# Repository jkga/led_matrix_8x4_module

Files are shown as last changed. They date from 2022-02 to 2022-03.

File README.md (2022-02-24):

# LED Matrix(8x4) Module
This repository aims to provide a basic program, schematic diagram, and PCB design for  an eight by four (8x4) LED matrix with Arduino and SN74HC595 shift register IC

## Sketch & Pin Configurations
> [Arduino Uno Sketch](./src/led_8x4.ino)

| | Module | Arduino 
| ---  | --- | ---
| Latch | L | 8 
| Serial Data Input | D | 11 
| Clock Input | C | 12 
| Row 1 | 4 | 4 
| Row 2 | 3 | 5
| Row 3 | 2 | 6
| Row 4 | 1 | 7
| Power (+) | + | 5v
| Power (-) | - | GND

## Bills of Materials

| QTY | Reference | Value 
| ---  | --- | ---
| 1 | C1 | 33uf 
| 1 | C2 | 0.1uf 
| 1 | C3 | 0.1uf 
| 32 | D1 - D32 | LED (Vfmin = 1.7v; Ifmax = 0.25mA)  
| 1 | J1 | 1x4 Female Connector  
| 1 | J2 | 1x4 Female Connector  
| 1 | J3 | 1x4 Female Connector 
| 1 | J4 | 2x8 DIP Socket  
| 8 | Q1 - Q8 | PN2222A BJT Transistor
| 8 | | 4.7k ohms
| 8 | | 510 ohms
| 1 | U1 | SN74HC595N  
| 10 | | Jumper Wires 

## Demo
> L.O.V.E - A Valentine's day message to everyone   

https://user-images.githubusercontent.com/10413754/155494353-f9fd05cc-bb8c-47e1-8aa6-f02e38358166.mp4

## Schematic Diagram
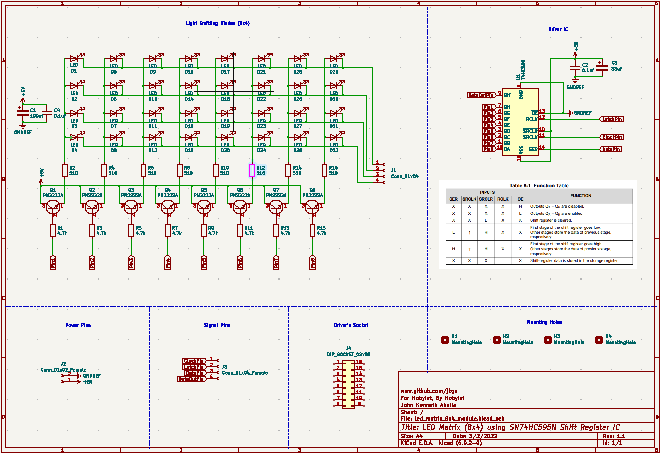
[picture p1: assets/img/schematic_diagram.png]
schematic_diagram


## Printed Circuit Board
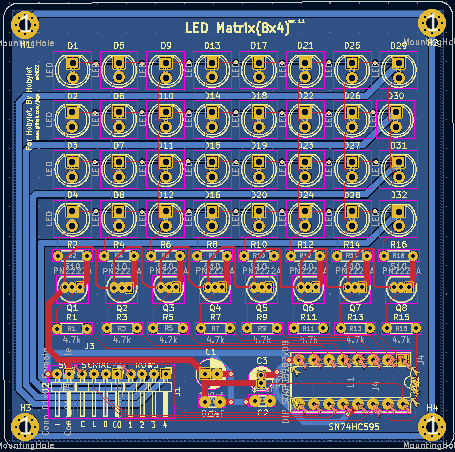
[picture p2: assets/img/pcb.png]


## Rendered Model
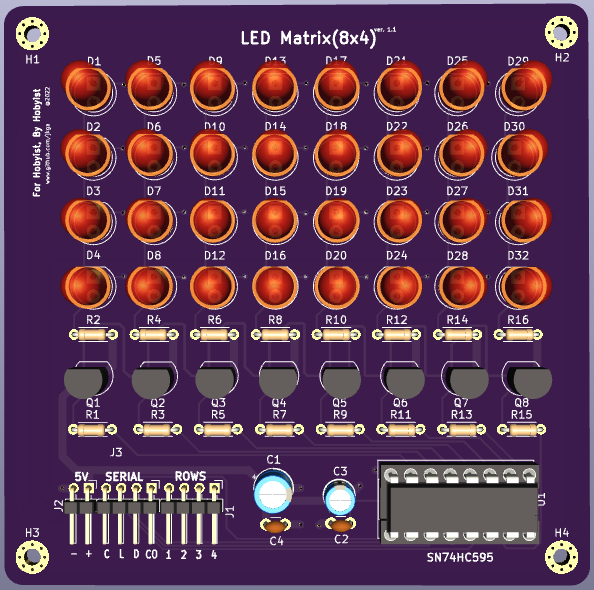
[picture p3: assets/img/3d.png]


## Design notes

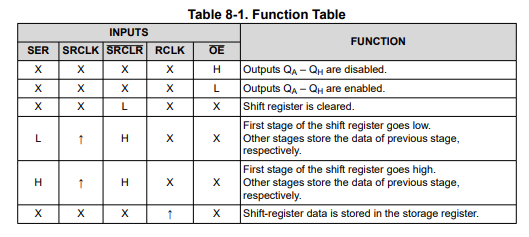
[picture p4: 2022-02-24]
kicad/sn74hc595 function table.png

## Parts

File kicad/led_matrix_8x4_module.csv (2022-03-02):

Source: | /Applications/XAMPP/xamppfiles/htdocs/led_matrix_8x4_module/kicad/led_matrix_8x4_module.kicad_sch
Date: | Wednesday, 02 March 2022 at 10:20:02
Tool: | Eeschema (6.0.2-0)
Generator: | /Applications/KiCad/KiCad.app/Contents/SharedSupport/plugins/bom_csv_grouped_by_value.py
Component Count: | 65
Individual Components:
Item | Qty | Reference(s) | Value | LibPart | Footprint | Datasheet
 |  | C1 | 100uf | Device:CP | Capacitor_THT:CP_Radial_D5.0mm_P2.00mm
 |  | C2 | 0.1uf | Device:C | Capacitor_THT:C_Disc_D3.0mm_W1.6mm_P2.50mm | ~
 |  | C3 | 33uf | Device:C_Polarized | Capacitor_THT:CP_Radial_D4.0mm_P1.50mm | ~
 |  | C4 | 0.1uf | Device:C | Capacitor_THT:C_Disc_D3.0mm_W1.6mm_P2.50mm | ~
 |  | D1 | LED | Device:LED | LED_THT:LED_D5.0mm | ~
 |  | D2 | LED | Device:LED | LED_THT:LED_D5.0mm | ~
 |  | D3 | LED | Device:LED | LED_THT:LED_D5.0mm | ~
 |  | D4 | LED | Device:LED | LED_THT:LED_D5.0mm | ~
 |  | D5 | LED | Device:LED | LED_THT:LED_D5.0mm | ~
 |  | D6 | LED | Device:LED | LED_THT:LED_D5.0mm | ~
 |  | D7 | LED | Device:LED | LED_THT:LED_D5.0mm | ~
 |  | D8 | LED | Device:LED | LED_THT:LED_D5.0mm | ~
 |  | D9 | LED | Device:LED | LED_THT:LED_D5.0mm | ~
 |  | D10 | LED | Device:LED | LED_THT:LED_D5.0mm | ~
 |  | D11 | LED | Device:LED | LED_THT:LED_D5.0mm | ~
 |  | D12 | LED | Device:LED | LED_THT:LED_D5.0mm | ~
 |  | D13 | LED | Device:LED | LED_THT:LED_D5.0mm | ~
 |  | D14 | LED | Device:LED | LED_THT:LED_D5.0mm | ~
 |  | D15 | LED | Device:LED | LED_THT:LED_D5.0mm | ~
 |  | D16 | LED | Device:LED | LED_THT:LED_D5.0mm | ~
 |  | D17 | LED | Device:LED | LED_THT:LED_D5.0mm | ~
 |  | D18 | LED | Device:LED | LED_THT:LED_D5.0mm | ~
 |  | D19 | LED | Device:LED | LED_THT:LED_D5.0mm | ~
 |  | D20 | LED | Device:LED | LED_THT:LED_D5.0mm | ~
 |  | D21 | LED | Device:LED | LED_THT:LED_D5.0mm | ~
 |  | D22 | LED | Device:LED | LED_THT:LED_D5.0mm | ~
 |  | D23 | LED | Device:LED | LED_THT:LED_D5.0mm | ~
 |  | D24 | LED | Device:LED | LED_THT:LED_D5.0mm | ~
 |  | D25 | LED | Device:LED | LED_THT:LED_D5.0mm | ~
 |  | D26 | LED | Device:LED | LED_THT:LED_D5.0mm | ~
 |  | D27 | LED | Device:LED | LED_THT:LED_D5.0mm | ~
 |  | D28 | LED | Device:LED | LED_THT:LED_D5.0mm | ~
 |  | D29 | LED | Device:LED | LED_THT:LED_D5.0mm | ~
 |  | D30 | LED | Device:LED | LED_THT:LED_D5.0mm | ~
 |  | D31 | LED | Device:LED | LED_THT:LED_D5.0mm | ~
 |  | D32 | LED | Device:LED | LED_THT:LED_D5.0mm | ~
 |  | J1 | Conn_01x04 | Connector:Conn_01x04_Female | Connector_PinHeader_2.00mm:PinHeader_1x04_P2.00mm_Horizontal | ~
 |  | J2 | Conn_01x02_Female | Connector:Conn_01x02_Female | Connector_PinHeader_2.00mm:PinHeader_1x02_P2.00mm_Horizontal | ~
 |  | J3 | Conn_01x04_Female | Connector:Conn_01x04_Female | Connector_PinHeader_2.00mm:PinHeader_1x04_P2.00mm_Horizontal | ~
 |  | J4 | DIP_SOCKET_02x08 | Connector_Generic:Conn_02x08_Counter_Clockwise | Package_DIP:DIP-16_W7.62mm_Socket | ~
 |  | Q1 | PN2222A | Transistor_BJT:PN2222A | Package_TO_SOT_THT:TO-92_Inline | https://www.onsemi.com/pub/Collateral/PN2222-D.PDF
 |  | Q2 | PN2222A | Transistor_BJT:PN2222A | Package_TO_SOT_THT:TO-92_Inline | https://www.onsemi.com/pub/Collateral/PN2222-D.PDF
 |  | Q3 | PN2222A | Transistor_BJT:PN2222A | Package_TO_SOT_THT:TO-92_Inline | https://www.onsemi.com/pub/Collateral/PN2222-D.PDF
 |  | Q4 | PN2222A | Transistor_BJT:PN2222A | Package_TO_SOT_THT:TO-92_Inline | https://www.onsemi.com/pub/Collateral/PN2222-D.PDF
 |  | Q5 | PN2222A | Transistor_BJT:PN2222A | Package_TO_SOT_THT:TO-92_Inline | https://www.onsemi.com/pub/Collateral/PN2222-D.PDF
 |  | Q6 | PN2222A | Transistor_BJT:PN2222A | Package_TO_SOT_THT:TO-92_Inline | https://www.onsemi.com/pub/Collateral/PN2222-D.PDF
 |  | Q7 | PN2222A | Transistor_BJT:PN2222A | Package_TO_SOT_THT:TO-92_Inline | https://www.onsemi.com/pub/Collateral/PN2222-D.PDF
 |  | Q8 | PN2222A | Transistor_BJT:PN2222A | Package_TO_SOT_THT:TO-92_Inline | https://www.onsemi.com/pub/Collateral/PN2222-D.PDF
 |  | R1 | 4.7k | Device:R | Resistor_THT:R_Axial_DIN0204_L3.6mm_D1.6mm_P5.08mm_Horizontal | ~
 |  | R2 | 510 | Device:R | Resistor_THT:R_Axial_DIN0204_L3.6mm_D1.6mm_P5.08mm_Horizontal | ~
 |  | R3 | 4.7k | Device:R | Resistor_THT:R_Axial_DIN0204_L3.6mm_D1.6mm_P5.08mm_Horizontal | ~
 |  | R4 | 510 | Device:R | Resistor_THT:R_Axial_DIN0204_L3.6mm_D1.6mm_P5.08mm_Horizontal | ~
 |  | R5 | 4.7k | Device:R | Resistor_THT:R_Axial_DIN0204_L3.6mm_D1.6mm_P5.08mm_Horizontal | ~
 |  | R6 | 510 | Device:R | Resistor_THT:R_Axial_DIN0204_L3.6mm_D1.6mm_P5.08mm_Horizontal | ~
 |  | R7 | 4.7k | Device:R | Resistor_THT:R_Axial_DIN0204_L3.6mm_D1.6mm_P5.08mm_Horizontal | ~
 |  | R8 | 510 | Device:R | Resistor_THT:R_Axial_DIN0204_L3.6mm_D1.6mm_P5.08mm_Horizontal | ~
 |  | R9 | 4.7k | Device:R | Resistor_THT:R_Axial_DIN0204_L3.6mm_D1.6mm_P5.08mm_Horizontal | ~
 |  | R10 | 510 | Device:R | Resistor_THT:R_Axial_DIN0204_L3.6mm_D1.6mm_P5.08mm_Horizontal | ~
 |  | R11 | 4.7k | Device:R | Resistor_THT:R_Axial_DIN0204_L3.6mm_D1.6mm_P5.08mm_Horizontal | ~
 |  | R12 | 510 | Device:R | Resistor_THT:R_Axial_DIN0204_L3.6mm_D1.6mm_P5.08mm_Horizontal | ~
 |  | R13 | 4.7k | Device:R | Resistor_THT:R_Axial_DIN0204_L3.6mm_D1.6mm_P5.08mm_Horizontal | ~
 |  | R14 | 510 | Device:R | Resistor_THT:R_Axial_DIN0204_L3.6mm_D1.6mm_P5.08mm_Horizontal | ~
 |  | R15 | 4.7k | Device:R | Resistor_THT:R_Axial_DIN0204_L3.6mm_D1.6mm_P5.08mm_Horizontal | ~
 |  | R16 | 510 | Device:R | Resistor_THT:R_Axial_DIN0204_L3.6mm_D1.6mm_P5.08mm_Horizontal | ~
 |  | U1 | 74HC595 | 74xx:74HC595 | Package_DIP:DIP-16_W7.62mm | http://www.ti.com/lit/ds/symlink/sn74hc595.pdf
Collated Components:
Item | Qty | Reference(s) | Value | LibPart | Footprint | Datasheet
1 | 1 | C1 | 100uf | Device:CP | Capacitor_THT:CP_Radial_D5.0mm_P2.00mm
2 | 2 | C2, C4 | 0.1uf | Device:C | Capacitor_THT:C_Disc_D3.0mm_W1.6mm_P2.50mm | ~
3 | 1 | C3 | 33uf | Device:C_Polarized | Capacitor_THT:CP_Radial_D4.0mm_P1.50mm | ~
4 | 32 | D1, D2, D3, D4, D5, D6, D7, D8, D9, D10, D11, D12, D13, D14, D15, D16, D17, D18, D19, D20, D21, D22, D23, D24, D25, D26, D27, D28, D29, D30, D31, D32 | LED | Device:LED | LED_THT:LED_D5.0mm | ~
5 | 1 | J1 | Conn_01x04 | Connector:Conn_01x04_Female | Connector_PinHeader_2.00mm:PinHeader_1x04_P2.00mm_Horizontal | ~
6 | 1 | J2 | Conn_01x02_Female | Connector:Conn_01x02_Female | Connector_PinHeader_2.00mm:PinHeader_1x02_P2.00mm_Horizontal | ~
7 | 1 | J3 | Conn_01x04_Female | Connector:Conn_01x04_Female | Connector_PinHeader_2.00mm:PinHeader_1x04_P2.00mm_Horizontal | ~
8 | 1 | J4 | DIP_SOCKET_02x08 | Connector_Generic:Conn_02x08_Counter_Clockwise | Package_DIP:DIP-16_W7.62mm_Socket | ~
9 | 8 | Q1, Q2, Q3, Q4, Q5, Q6, Q7, Q8 | PN2222A | Transistor_BJT:PN2222A | Package_TO_SOT_THT:TO-92_Inline | https://www.onsemi.com/pub/Collateral/PN2222-D.PDF
10 | 8 | R1, R3, R5, R7, R9, R11, R13, R15 | 4.7k | Device:R | Resistor_THT:R_Axial_DIN0204_L3.6mm_D1.6mm_P5.08mm_Horizontal | ~
11 | 8 | R2, R4, R6, R8, R10, R12, R14, R16 | 510 | Device:R | Resistor_THT:R_Axial_DIN0204_L3.6mm_D1.6mm_P5.08mm_Horizontal | ~
12 | 1 | U1 | 74HC595 | 74xx:74HC595 | Package_DIP:DIP-16_W7.62mm | http://www.ti.com/lit/ds/symlink/sn74hc595.pdf

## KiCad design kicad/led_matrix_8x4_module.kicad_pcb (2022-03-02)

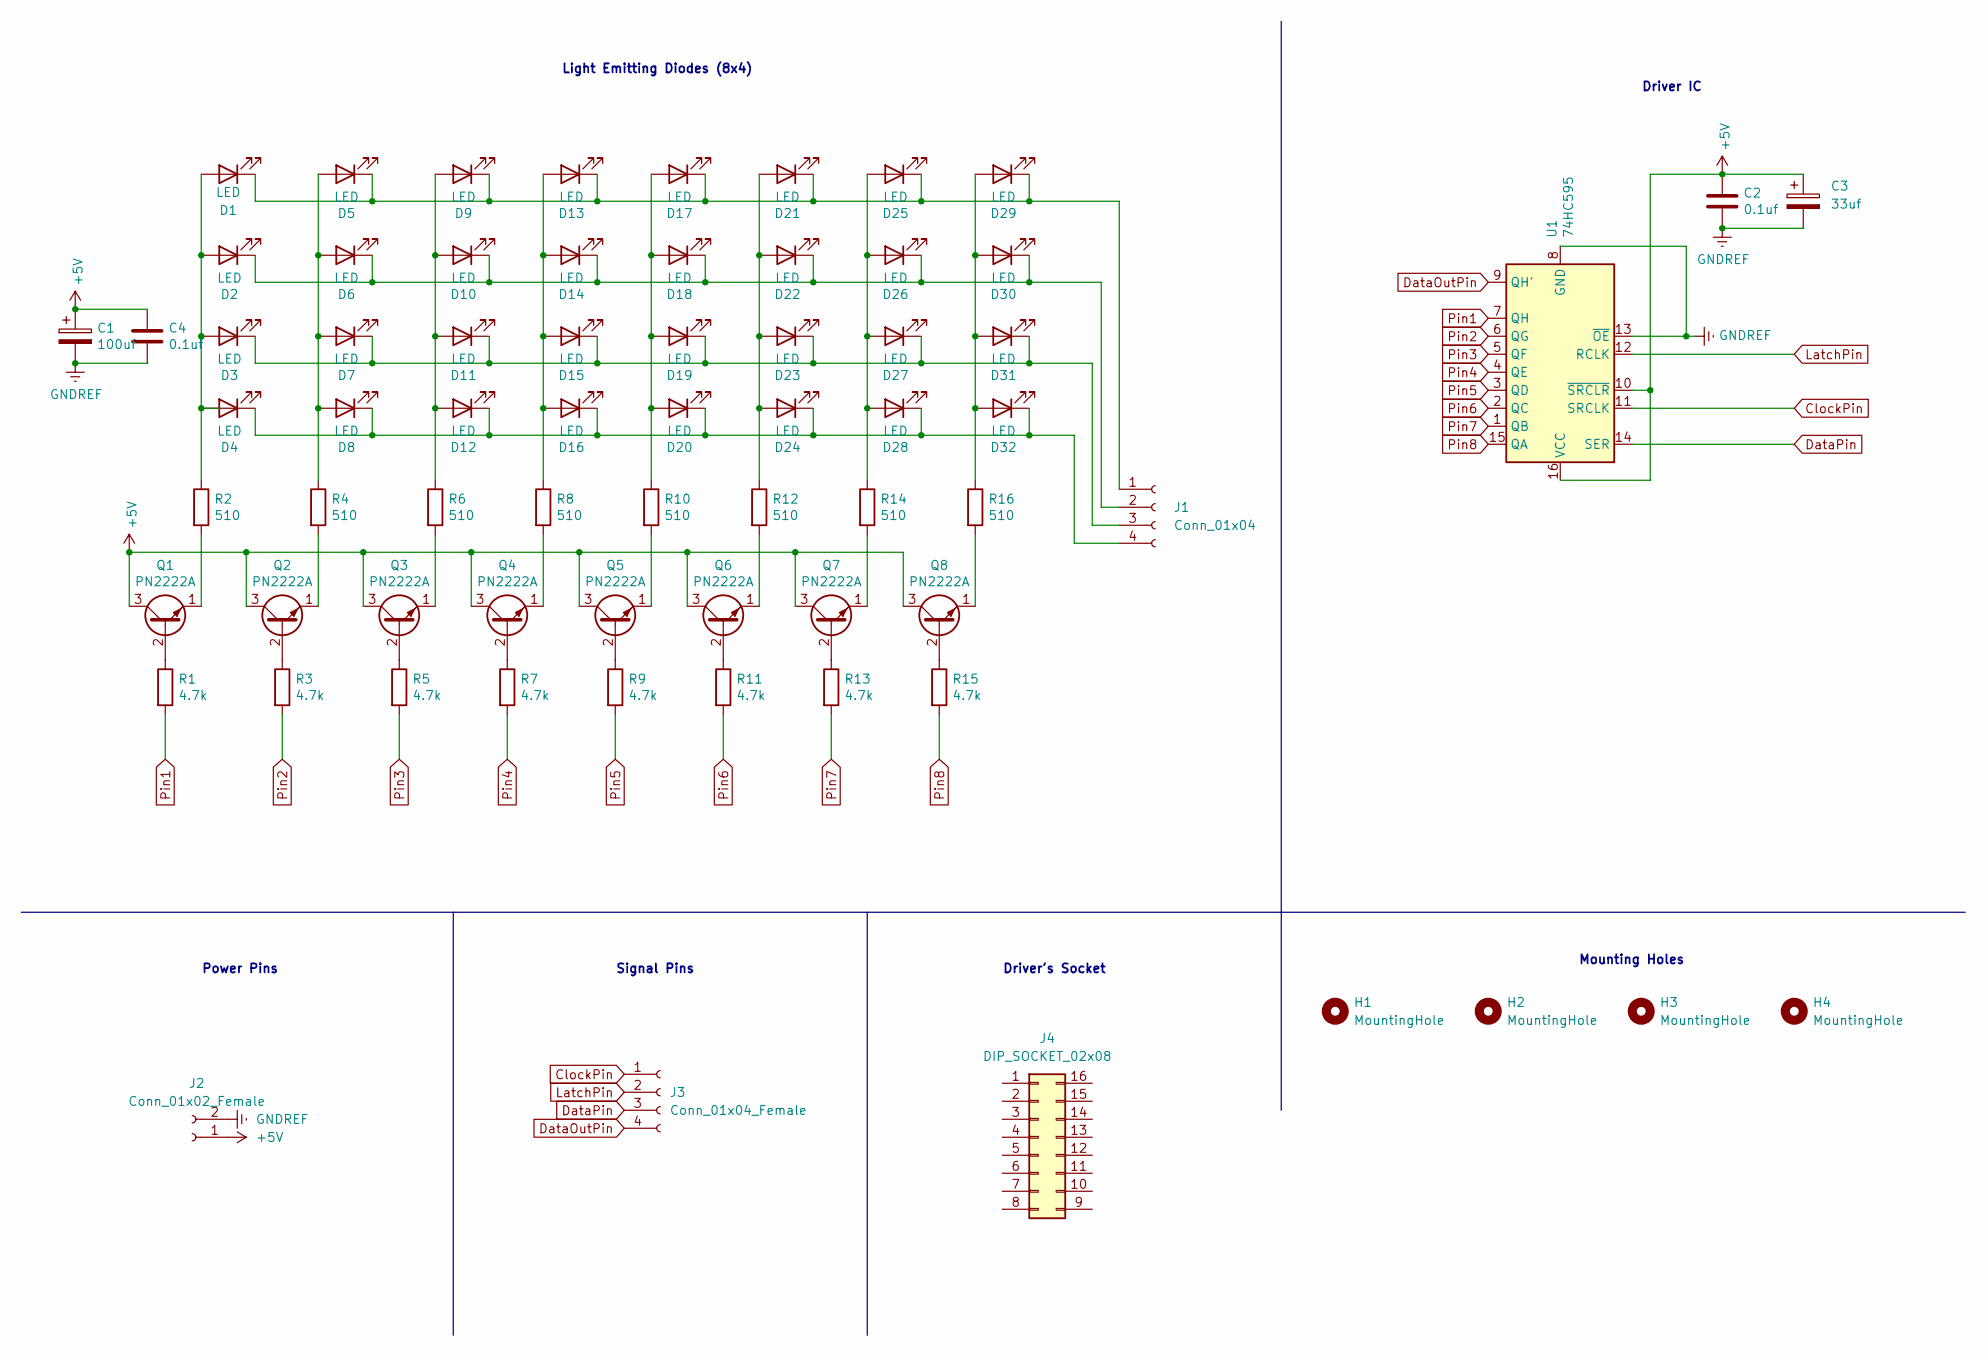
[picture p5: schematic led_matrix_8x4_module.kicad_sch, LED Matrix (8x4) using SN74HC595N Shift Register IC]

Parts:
C1: 100uf; CP_Radial_D5.0mm_P2.00mm
C2, C4: 0.1uf; C_Disc_D3.0mm_W1.6mm_P2.50mm
C3: 33uf; CP_Radial_D4.0mm_P1.50mm
D1, D2, D3, D4, D5, D6, D7, D8, D9, D10, D11, D12, D13, D14, D15, D16, D17, D18, D19, D20, D21, D22, D23, D24, D25, D26, D27, D28, D29, D30, D31, D32: LED; LED_D5.0mm
H1, H2, H3, H4: MountingHole; MountingHole_2.2mm_M2_Pad_Via
J1: Conn_01x04; PinHeader_1x04_P2.00mm_Horizontal
J2: Conn_01x02_Female; PinHeader_1x02_P2.00mm_Horizontal
J3: Conn_01x04_Female; PinHeader_1x04_P2.00mm_Horizontal
J4: DIP_SOCKET_02x08; DIP-16_W7.62mm_Socket
Q1, Q2, Q3, Q4, Q5, Q6, Q7, Q8: PN2222A; TO-92_Inline
R1, R3, R5, R7, R9, R11, R13, R15: 4.7k; R_Axial_DIN0204_L3.6mm_D1.6mm_P5.08mm_Horizontal
R2, R4, R6, R8, R10, R12, R14, R16: 510; R_Axial_DIN0204_L3.6mm_D1.6mm_P5.08mm_Horizontal
U1: 74HC595; DIP-16_W7.62mm

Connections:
+5V: C1.1, C2.1, C3.1, C4.1, J2.1, Q1.3 (C), Q2.3 (C), Q3.3 (C), Q4.3 (C), Q5.3 (C), Q6.3 (C), Q7.3 (C), Q8.3 (C), U1.10 (~SRCLR), U1.16 (VCC)
ClockPin: J3.1, U1.11 (SRCLK)
DataOutPin: J3.4, U1.9 (QH')
DataPin: J3.3, U1.14 (SER)
GNDREF: C1.2, C2.2, C3.2, C4.2, J2.2, U1.8 (GND), U1.13 (~OE)
LatchPin: J3.2, U1.12 (RCLK)
unnamed: D1.1 (K), D5.1 (K), D9.1 (K), D13.1 (K), D17.1 (K), D21.1 (K), D25.1 (K), D29.1 (K), J1.1
unnamed: D1.2 (A), D2.2 (A), D3.2 (A), D4.2 (A), R2.1
unnamed: D5.2 (A), D6.2 (A), D7.2 (A), D8.2 (A), R4.1
unnamed: D2.1 (K), D6.1 (K), D10.1 (K), D14.1 (K), D18.1 (K), D22.1 (K), D26.1 (K), D30.1 (K), J1.2
unnamed: D9.2 (A), D10.2 (A), D11.2 (A), D12.2 (A), R6.1
unnamed: D3.1 (K), D7.1 (K), D11.1 (K), D15.1 (K), D19.1 (K), D23.1 (K), D27.1 (K), D31.1 (K), J1.3
unnamed: D4.1 (K), D8.1 (K), D12.1 (K), D16.1 (K), D20.1 (K), D24.1 (K), D28.1 (K), D32.1 (K), J1.4
unnamed: D13.2 (A), D14.2 (A), D15.2 (A), D16.2 (A), R8.1
unnamed: D17.2 (A), D18.2 (A), D19.2 (A), D20.2 (A), R10.1
unnamed: D21.2 (A), D22.2 (A), D23.2 (A), D24.2 (A), R12.1
unnamed: D25.2 (A), D26.2 (A), D27.2 (A), D28.2 (A), R14.1
unnamed: D29.2 (A), D30.2 (A), D31.2 (A), D32.2 (A), R16.1
unnamed: Q1.1 (E), R2.2
unnamed: Q1.2 (B), R1.1
unnamed: Q2.1 (E), R4.2
unnamed: Q2.2 (B), R3.1
unnamed: Q3.1 (E), R6.2
unnamed: Q3.2 (B), R5.1
unnamed: Q4.1 (E), R8.2
unnamed: Q4.2 (B), R7.1
unnamed: Q5.1 (E), R10.2
unnamed: Q5.2 (B), R9.1
unnamed: Q6.1 (E), R12.2
unnamed: Q6.2 (B), R11.1
unnamed: Q7.1 (E), R14.2
unnamed: Q7.2 (B), R13.1
unnamed: Q8.1 (E), R16.2
unnamed: Q8.2 (B), R15.1
Pin1: R1.2, U1.7 (QH)
Pin2: R3.2, U1.6 (QG)
Pin3: R5.2, U1.5 (QF)
Pin4: R7.2, U1.4 (QE)
Pin5: R9.2, U1.3 (QD)
Pin6: R11.2, U1.2 (QC)
Pin7: R13.2, U1.1 (QB)
Pin8: R15.2, U1.15 (QA)

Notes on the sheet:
Driver IC
Light Emitting Diodes (8x4)
Mounting Holes
Driver's Socket
Power Pins
Signal Pins

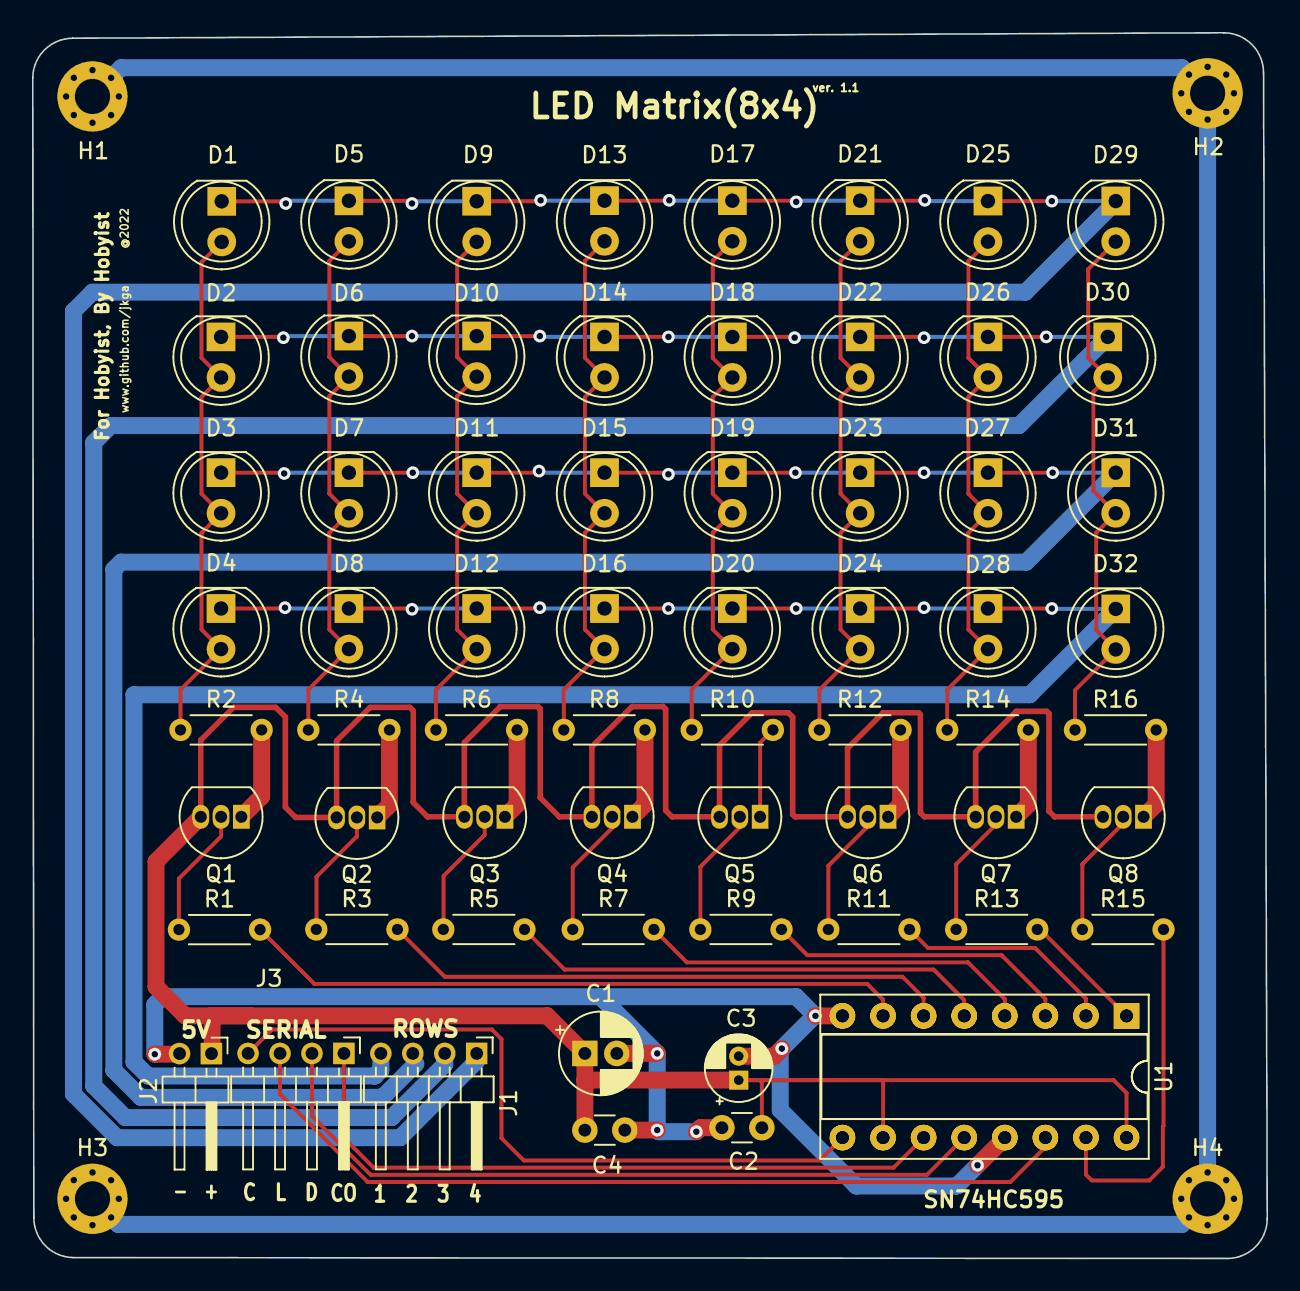
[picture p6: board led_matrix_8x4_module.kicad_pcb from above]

Board: 2 copper layers, 77.3 x 76.7 mm, 69 parts (0 on the bottom side), 42 nets.

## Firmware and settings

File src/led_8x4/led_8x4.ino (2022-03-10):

//74HC595N pins
#define latchPin 8
#define dataPin 11
#define clockPin 12

//vertical pins
#define row1Pin 4
#define row2Pin 5
#define row3Pin 6
#define row4Pin 7

const char pins[] = {
  row1Pin,
  row2Pin,
  row3Pin,
  row4Pin
};


//characters in binary
unsigned int charA[4][8] = {
  {0,0,0,1,1,0,0,0},
  {0,0,1,0,0,1,0,0},
  {0,0,1,1,1,1,0,0},
  {0,0,1,0,0,1,0,0}
};

unsigned int charB[4][8] = {
  {0,0,1,1,1,1,0,0},
  {0,0,1,0,1,1,0,0},
  {0,0,1,1,0,1,0,0},
  {0,0,1,1,1,1,0,0}
};

unsigned  int charC[4][8] = {
  {0,0,1,1,1,1,0,0},
  {0,0,1,0,0,0,0,0},
  {0,0,1,0,0,0,0,0},
  {0,0,1,1,1,1,0,0}
};

unsigned int charD[4][8] = {
  {0,0,1,1,1,0,0,0},
  {0,0,1,0,0,1,0,0},
  {0,0,1,0,0,1,0,0},
  {0,0,1,1,1,0,0,0}
};

unsigned int charE[4][8] = {
  {0,0,1,1,1,1,0,0},
  {0,0,1,1,1,1,0,0},
  {0,0,1,0,0,0,0,0},
  {0,0,1,1,1,1,0,0}
};

unsigned int charF[4][8] = {
  {0,0,1,1,1,1,0,0},
  {0,0,1,0,0,0,0,0},
  {0,0,1,1,1,1,0,0},
  {0,0,1,0,0,0,0,0}
};

unsigned int charG[4][8] = {
  {0,0,0,1,1,0,0,0},
  {0,0,1,0,0,0,0,0},
  {0,0,1,0,1,1,0,0},
  {0,0,1,1,1,1,0,0}
};

unsigned int charH[4][8] = {
  {0,0,1,0,0,1,0,0},
  {0,0,1,1,1,1,0,0},
  {0,0,1,1,1,1,0,0},
  {0,0,1,0,0,1,0,0}
};

unsigned int charI[4][8] = {
  {0,0,1,1,1,1,0,0},
  {0,0,0,1,1,0,0,0},
  {0,0,0,1,1,0,0,0},
  {0,0,1,1,1,1,0,0}
};

unsigned int charJ[4][8] = {
  {0,0,0,0,0,1,0,0},
  {0,0,0,0,0,1,0,0},
  {0,0,1,0,0,1,0,0},
  {0,0,1,1,1,1,0,0}
};

unsigned int charK[4][8] = {
  {0,0,1,0,0,1,0,0},
  {0,0,1,1,1,0,0,0},
  {0,0,1,0,1,0,0,0},
  {0,0,1,0,0,1,0,0}
};

unsigned int charL[4][8] = {
  {0,0,1,0,0,0,0,0},
  {0,0,1,0,0,0,0,0},
  {0,0,1,0,0,0,0,0},
  {0,0,1,1,1,1,0,0}
};

unsigned int charM[4][8] = {
  {0,0,1,0,0,1,0,0},
  {0,0,1,1,1,1,0,0},
  {0,0,1,0,0,1,0,0},
  {0,0,1,0,0,1,0,0}
};

unsigned int charN[4][8] = {
  {0,0,1,0,0,1,0,0},
  {0,0,1,1,0,1,0,0},
  {0,0,1,0,1,1,0,0},
  {0,0,1,0,0,1,0,0}
};

unsigned int charO[4][8] = {
  {0,0,1,1,1,1,0,0},
  {0,0,1,0,0,1,0,0},
  {0,0,1,0,0,1,0,0},
  {0,0,1,1,1,1,0,0}
};

unsigned int charP[4][8] = {
  {0,0,1,1,1,1,0,0},
  {0,0,1,1,1,1,0,0},
  {0,0,1,0,0,0,0,0},
  {0,0,1,0,0,0,0,0}
};

int charQ[4][8] = {
  {0,0,1,1,1,1,0,0},
  {0,0,1,0,0,1,0,0},
  {0,0,1,0,1,1,0,0},
  {0,0,1,1,1,1,0,0}
};

unsigned int charR[4][8] = {
  {0,0,1,1,1,1,0,0},
  {0,0,1,0,1,1,0,0},
  {0,0,1,1,1,0,0,0},
  {0,0,1,0,0,1,0,0}
};

unsigned int charS[4][8] = {
  {0,0,1,1,1,1,0,0},
  {0,0,1,0,0,0,0,0},
  {0,0,0,1,1,1,0,0},
  {0,0,1,1,1,1,0,0}
};

unsigned int charT[4][8] = {
  {0,0,1,1,1,1,0,0},
  {0,0,0,1,1,0,0,0},
  {0,0,0,1,1,0,0,0},
  {0,0,0,1,1,0,0,0}
};

unsigned int charU[4][8] = {
  {0,0,1,0,0,1,0,0},
  {0,0,1,0,0,1,0,0},
  {0,0,1,0,0,1,0,0},
  {0,0,1,1,1,1,0,0}
};

unsigned int charV[4][8] = {
  {0,0,1,0,0,1,0,0},
  {0,0,1,0,0,1,0,0},
  {0,0,1,0,0,1,0,0},
  {0,0,0,1,1,0,0,0}
};

unsigned int charW[4][8] = {
  {0,0,1,0,0,1,0,0},
  {0,0,1,0,0,1,0,0},
  {0,0,1,1,1,1,0,0},
  {0,0,1,0,0,1,0,0}
};

unsigned int charX[4][8] = {
  {0,0,1,0,0,1,0,0},
  {0,0,0,1,1,0,0,0},
  {0,0,0,1,1,0,0,0},
  {0,0,1,0,0,1,0,0}
};

unsigned int charY[4][8] = {
  {0,0,1,0,0,1,0,0},
  {0,0,0,1,1,0,0,0},
  {0,0,0,1,1,0,0,0},
  {0,0,0,1,1,0,0,0}
};

int charZ[4][8] = {
  {0,0,1,1,1,1,0,0},
  {0,0,0,0,1,0,0,0},
  {0,0,0,1,0,0,0,0},
  {0,0,1,1,1,1,0,0}
};

unsigned int charHeart[4][8] = {
  {0,1,1,0,0,1,1,0},
  {0,1,1,1,1,1,1,0},
  {0,0,1,1,1,1,0,0},
  {0,0,0,1,1,0,0,0}
};


unsigned int board8x4[4][8] = {
  {0,0,0,0,0,0,0,0},
  {0,0,0,0,0,0,0,0},
  {0,0,0,0,0,0,0,0},
  {0,0,0,0,0,0,0,0}
};

int binToDec (char *bin) {
   int decVal = 0;
    for (int i=0; i< strlen(bin); i++)
    {
      decVal *= 2;
      if (bin[i] == '1') decVal++;
    }
    return decVal;
}

char* join(int *chars) {
  char* dd = malloc(1);
  char buffer[8];
  for(int x = 0; x < 8; x++) {
    sprintf(buffer, "%d", chars[x]);
    strcat(dd, buffer);
  }
  return dd;
}

int currentRow = 0;
int currentDisplayColumIndex = 0;

unsigned long startMillis;
unsigned long currentMillis;
const unsigned long period = 100;


int displaySingleLetter (int character[][8]) {

    for (int row = 0; row < 4; row++) {

      digitalWrite(latchPin, LOW);
      
      //join array and convert to decimal value
      char *charByte = join(character[row]);
      int val = binToDec(charByte);

      // shift out the bits:
      shiftOut(dataPin, clockPin, LSBFIRST, val);
      //take the latch pin high so the LEDs will light up:
      digitalWrite(latchPin, HIGH);

      //freeup memory
      free(charByte);
        
      //disable y axis
      for(int x = 0; x < 4; x++) {
        if(x != currentRow) {
          pinMode(pins[x], INPUT);
        } else {
          pinMode(pins[currentRow], OUTPUT);
          digitalWrite(pins[currentRow], LOW);
        }
      }
      
      //point to next line 
      currentRow++;
         
      // reset row to zero if reached 4 lines
      if(currentRow >= 4 ) currentRow = 0;
      
      // pause before next row
      delay(5);
    }
    return 0;
}

int writeToColumn8x4Board(int board[4][8], int pos, int rowBits[4]) {

   for(int y = 0; y < 4; y++) {
     // write new data
      board[y][pos] = rowBits[y];
   }
   return 1;
}

int shift8x4BoardToLeft(int board[4][8]) {
   for(int y = 0; y < 4; y++) {
    int temp;
    int next = 0;
    for(int z = 0; z < 8; z++) {
      next = z+1;
      // write new data
      if(next <= 7) {
        temp = board[y][next];
        board[y][z] = temp;
      }
    }
   }
   return 1;
}

int* getColumnOf8x4Character(int chars[4][8], int columnPos) {
  static int rows[4]={0,1,1,0};
  for(int x=0; x < 4; x++) {
    for(int j=0; j<8; j++) {
      if(j==columnPos) rows[x] = chars[x][j];
    }
  } 
  return rows;
}

void setup() {
  //set pins to output
  pinMode(latchPin, OUTPUT);
  pinMode(clockPin, OUTPUT);
  pinMode(dataPin, OUTPUT);
  
  //set pins to high impedance
  pinMode(row1Pin, INPUT);
  pinMode(row2Pin, INPUT);
  pinMode(row3Pin, INPUT);
  pinMode(row4Pin, INPUT);
  startMillis = millis();
}


int letterIndex = 0;

int scrollText(int board8x4, int letters[], int letterCount, int columnCount) {
  int *bits = malloc(1);
  currentMillis = millis();

  if (currentMillis - startMillis >= period)
  {
    //use current time as start time
    startMillis = currentMillis;
    currentDisplayColumIndex++;
    free(bits);

    //point the cursor to the first element in the array of letters
    if(currentDisplayColumIndex > columnCount - 1) {
      letterIndex++;
      currentDisplayColumIndex = 0; 
    }
    if(letterIndex > letterCount - 1) letterIndex = 0;

    shift8x4BoardToLeft(board8x4);
  }

  bits= {getColumnOf8x4Character(letters[letterIndex], currentDisplayColumIndex)};
  int reversedColumnIndex = 7-currentDisplayColumIndex;
  writeToColumn8x4Board(board8x4, 7, bits); 
  displaySingleLetter(board8x4);
}

/*const int letters[] = {
  charA,
  charB,
  charC,
  charD,
  charE,
  charF,
  charG,
  charH,
  charI,
  charJ,
  charK,
  charL,
  charM,
  charN,
  charO,
  charP,
  charQ,
  charR,
  charS,
  charT,
  charU,
  charV,
  charW,
  charX,
  charY,
  charZ,
  charHeart
};*/


  
void loop() {
  const int letters[] = {
    charL,
    charO,
    charV,
    charE,
    charHeart
  };
  scrollText(board8x4, letters, sizeof(letters) / sizeof(int), 8);
}

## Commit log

2022-02-24 feat: add sketch and kicad files
    [led_matrix_8x4_module.csv, led_matrix_8x4_module.kicad_pcb, led_matrix_8x4_module.kicad_sch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]
2022-03-02 release: v1.1
    [led_matrix_8x4_module.csv, led_matrix_8x4_module.kicad_pcb, led_matrix_8x4_module.kicad_sch]
2022-03-10 fix: add break in declared variable inside loop
    [led_8x4.ino]
